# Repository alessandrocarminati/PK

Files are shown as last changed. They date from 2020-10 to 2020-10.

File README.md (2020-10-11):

# Password keeper 
The password keeper is a toy device for storing the personal password, and type them quickly.
The device can store up to 8 different passwords, no more than 16 chars each with 8 tags no more than 8 chars each.
One of the two buttons on the device allows the user to select the intended password and while the other allows to type it.
One two lines Hitachi HD44780 compatible display allows the user to see the tag associated with the password before typing it.
Relevant features of this project are as follows:
* The main MCU is an AVR ATTINY 85 @16MHz
* Just one MCU GPIO is used to drive the display
* The device presents itself as a keyboard, and it allows using just the USB keyboard interface to update the password DB
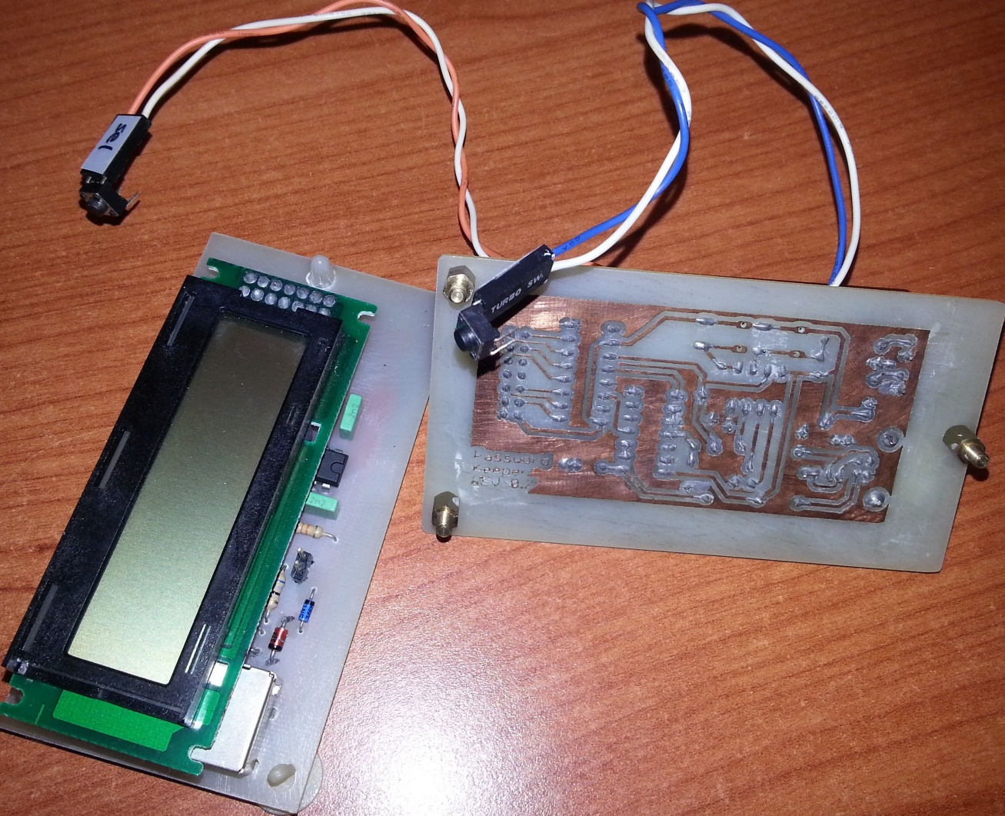
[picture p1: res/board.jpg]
design


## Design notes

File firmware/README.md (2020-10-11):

# Passwork keeper device firmware
The firmware is meant to be compiled by using the Arduino IDE and the Adafruit Trinket extension

https://adafruit.github.io/arduino-board-index/package_adafruit_index.json

The target AtTiny85 is assumed to be 16MHz, and to have the USBtinyISP boot loader already installed.

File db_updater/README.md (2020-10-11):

# Passwork keeper database updater
Straightforward utility. It gets a password file as argument and pushes it into the device using keyboard LEDs.
The three LEDs on the keyboard are used as lines of synchronous serial communication.
**makedb.c**  can be used to create a new database
**update.c** is the utility used for the actual update

*Example*
```
[edit makedb.c and put your password data. Remeber data is meant to be usb keyboard scancodes. Refer to usb_hid_keys.h]
gcc -o makedb makedb.c
./makedb >data
gcc -o updater updater.c
./updater data
```

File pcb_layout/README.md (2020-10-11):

#Password keeper PCB
The current repository implements the following schema

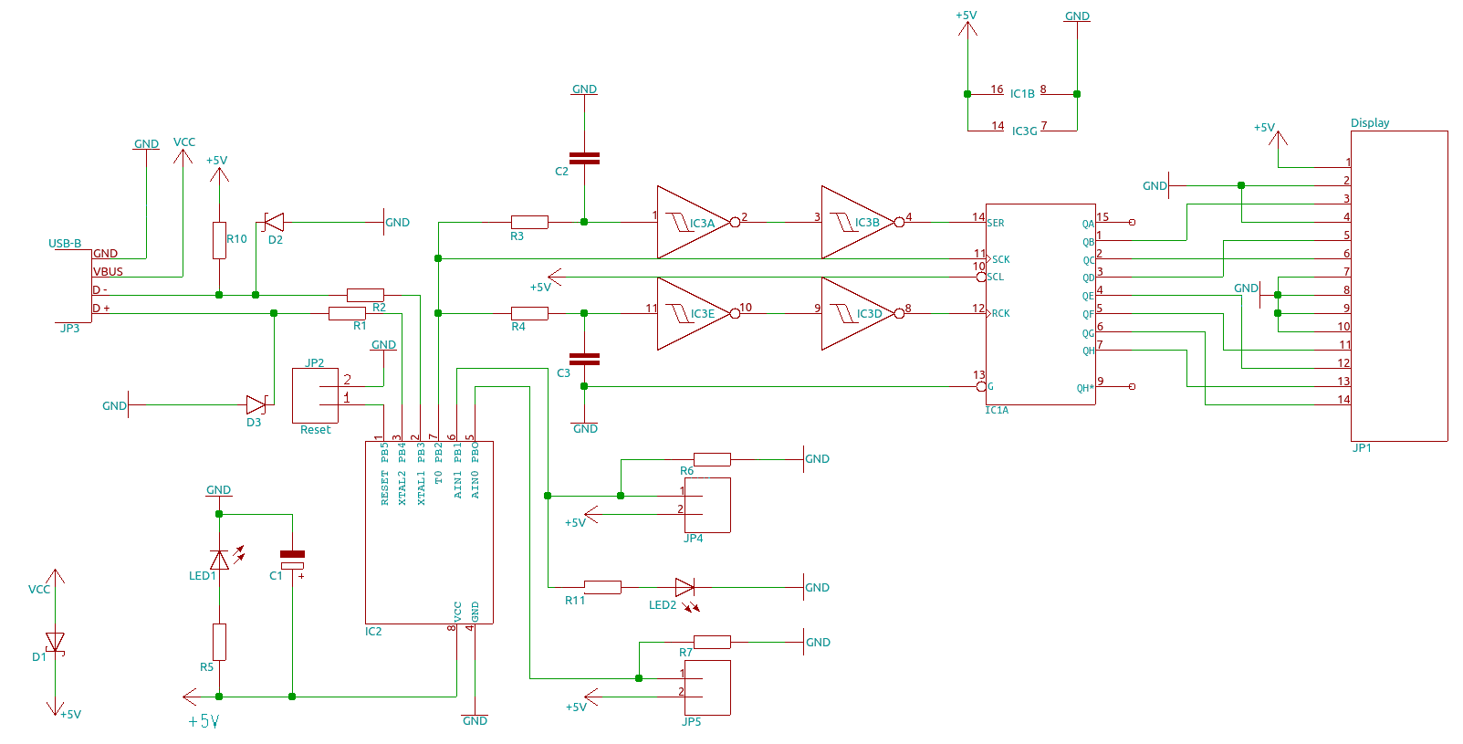
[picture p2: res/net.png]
NET


Because it is printed by hand, an effort is made to keep it single face.

Here the routed PCB

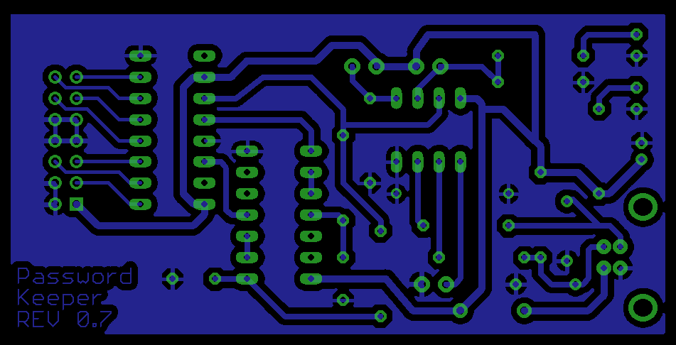
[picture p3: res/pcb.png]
LAYOUT


# BOM
| ID | Name | Package | Qty | Designation
|----|---|---|-----|---
|  1 | IC1 | DIL16 | 1 | 74HC595N
|  2 | IC2 | DIL08 | 1 | ATtiny85-20PU
|  3 | IC3 | DIL14 | 1 | CD40106BCN
|  4 | R1, R2 | 0207/10 | 2 | 68 $\Omega$
|  5 | R3 | 0207/10 | 1 | 33k $\Omega$
|  6 | R4 | 0207/10 | 1 | 220k $\Omega$
|  7 | R5 | 0207/10 | 1 | 560 $\Omega$ 
|  8 | R6, R7 | 0207/10 | 2 | 10k $\Omega$
|  9 | R10 | 0207/10 | 1 | 1.5k $\Omega$ 
| 10 | R11 | 0207/10 | 1 | 470 $\Omega$ 
| 11 | D1 | DO35 | 1 | 1N581
| 12 | D2, D3 | DO35 | 2 | 1N5227B-TR
| 13 | LED1 | LED5MM | 1 | Power
| 14 | LED2 | LED5MM | 1 | ACT
| 15 | C1 | E2-5 | 1 | 10$\mu$F
| 16 | C2, C3 | C050-024X044 | 2 | 2.2nF
| 17 | J1 | 2X07_LOCK | 1 | Display Connector
| 18 | JP3 | USB-B-PTH | 1 | USB-B
| 19 | JP2 | 1X02_LOCK | 1 | Reset
| 20 | JP4 | 1X02_LOCK | 1 | Button1
| 21 | JP5 | 1X02_LOCK | 1 | Button2
| 22 | DISPLAY  | NA | 1 | LM16211

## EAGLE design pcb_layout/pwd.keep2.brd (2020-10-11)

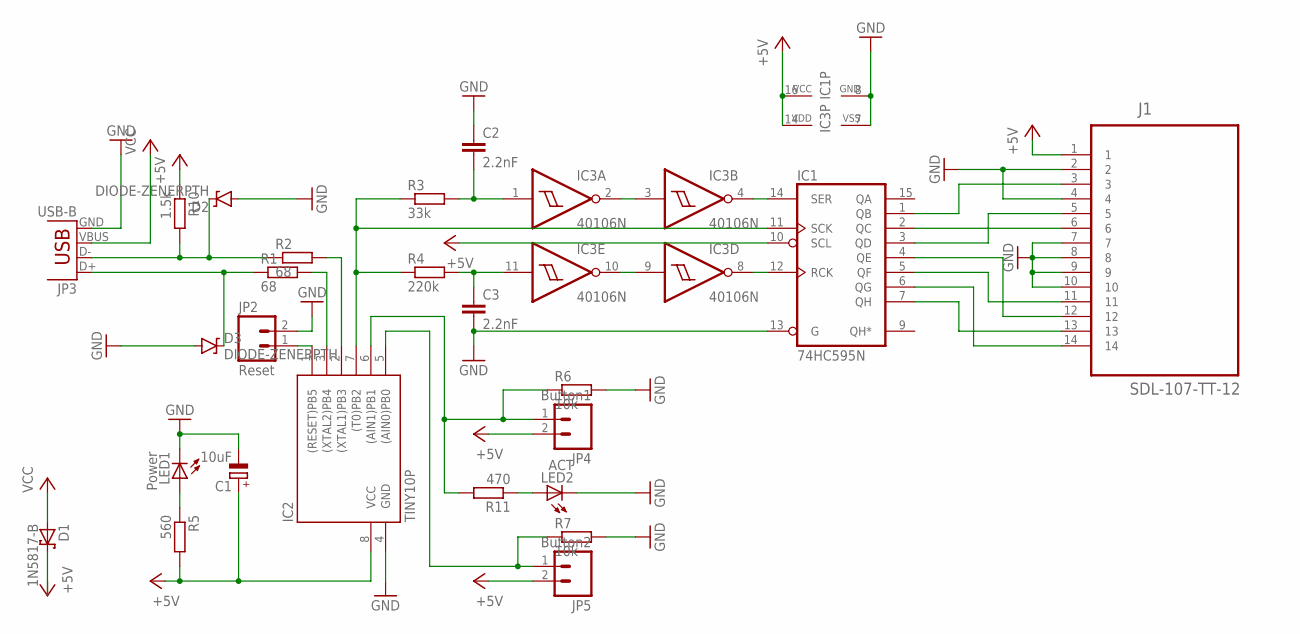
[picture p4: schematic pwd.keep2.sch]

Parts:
C1: 10uF; E2-5
C2, C3: 2.2nF; C050-024X044
D1: 1N5817-B; DO41-7.6
D2, D3: DIODE-ZENERPTH; DIODE-ZENER
IC1: 74HC595N; DIL16
IC2: TINY10P; DIL08
IC3: 40106N; DIL14
J1: SDL-107-TT-12; SAMTEC_SDL-107-TT-12
JP2: Reset; 1X02_LOCK
JP3: USB-B; USB-B-PTH
JP4: Button1; 1X02_LOCK
JP5: Button2; 1X02_LOCK
LED1: Power; LED5MM
LED2: ACT; LED5MM
R1, R2: 68; 0207/10
R3: 33k; 0207/10
R4: 220k; 0207/10
R5: 560; 0207/10
R6, R7: 10k; 0207/10
R10: 1.5k; 0207/10
R11: 470; 0207/10

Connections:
+5V: C1.+, D1.C, IC1.10 (SCL), IC1.16 (VCC), IC2.8 (VCC), IC3.14 (VDD), J1.1, JP4.2, JP5.2, R5.2, R10.1
GND: C1.-, C2.1, C3.2, D2.P$2 (A), D3.P$2 (A), IC1.8 (GND), IC1.13 (G), IC2.4 (GND), IC3.7 (VSS), J1.2, J1.4, J1.7, J1.8, J1.9, J1.10, JP2.2, JP3.GND, LED1.K (C), LED2.K (C), R6.2, R7.2
unnamed: IC1.7 (QH), J1.13
unnamed: IC1.6 (QG), J1.14
unnamed: IC1.5 (QF), J1.11
unnamed: IC1.4 (QE), J1.12
unnamed: IC1.3 (QD), J1.5
unnamed: IC1.2 (QC), J1.6
unnamed: IC1.1 (QB), J1.3
unnamed: D3.P$1 (C), JP3.D+, R1.1
unnamed: IC2.3 ((XTAL2)PB4), R1.2
unnamed: D2.P$1 (C), JP3.D-, R2.1, R10.2
unnamed: IC2.2 ((XTAL1)PB3), R2.2
unnamed: IC2.1 ((RESET)PB5), JP2.1
unnamed: LED2.A, R11.1
unnamed: LED1.A, R5.1
unnamed: IC1.11 (SCK), IC2.7 ((T0)PB2), R3.1, R4.1
unnamed: C3.1, IC3.11 (I), R4.2
unnamed: C2.2, IC3.1 (I), R3.2
unnamed: IC2.6 ((AIN1)PB1), JP4.1, R6.1, R11.2
unnamed: IC3.2 (O), IC3.3 (I)
unnamed: IC2.5 ((AIN0)PB0), JP5.1, R7.1
unnamed: IC1.14 (SER), IC3.4 (O)
unnamed: IC1.12 (RCK), IC3.8 (O)
unnamed: IC3.9 (I), IC3.10 (O)
VCC: D1.A, JP3.VBUS

Board: 2 copper layers, 25 parts (0 on the bottom side), 26 nets, no tracks yet.

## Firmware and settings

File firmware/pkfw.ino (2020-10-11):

#include <TrinketKeyboard.h>
#include <EEPROM.h>
#define SETUP_IDX 8
#define BROWSEPIN 0
#define ENTERPIN 1
#define DATAPIN 2
char UPDATE_STR[] = {'U','p','d','a','t','e',' ','p','s','w',' ','D','B','\0','\0','\0'};
char label[8];
char pswd[16];
unsigned char index, releasedB,releasedE;


void LCD1WireSend(unsigned char b) {
	char i;  //28 0010 1000

	for (i=7;i>0;i--) {
		if ((b>>i)&0x1) { // send 1
			digitalWrite(DATAPIN,LOW);
			delayMicroseconds(2);
			digitalWrite(DATAPIN,HIGH);
			delayMicroseconds(200);
			} else { // send 0
				digitalWrite(DATAPIN,LOW);
				delayMicroseconds(120);
				digitalWrite(DATAPIN,HIGH);
				delayMicroseconds(480);
				}
			}
	// send latch
	digitalWrite(DATAPIN,LOW);
	delayMicroseconds(460);
	digitalWrite(DATAPIN,HIGH);
	delayMicroseconds(1700);
	TrinketKeyboard.poll();
}

void LCDinit() {

	LCD1WireSend(0x28);
	LCD1WireSend(0x20); //init 4bit mode
	LCD1WireSend(0x08); 
	LCD1WireSend(0x00); //first nibble
	LCD1WireSend(0xc8);
	LCD1WireSend(0xc0); //second nibble clearscreen home show cursor
}

void LCDChar(unsigned char c) {
	LCD1WireSend( (c & 0xf0) | 0x0a);
	LCD1WireSend( (c & 0xf0) | 0x02);
	LCD1WireSend( c<<4 | 0x0a);
	LCD1WireSend( c<<4 | 0x02);
}

void LCDWrite(char *st) {

	while (*st != 0) {
		LCDChar(*st);
		st++;
		}
}

void LCDClear() {

	LCD1WireSend(0x08);
	LCD1WireSend(0x00); //first nibble
	LCD1WireSend(0xf8);
	LCD1WireSend(0xf0); //second nibble clearscreen home show cursor
}

void LCDGotoN(unsigned char n){

	 LCD1WireSend(0x88|n&70);
	 LCD1WireSend(0x80|n&70);
	 LCD1WireSend(n<<4|0x8);
	 LCD1WireSend(n<<4);
}

void LCDCLS() {
	LCD1WireSend(0x08);
	LCD1WireSend(0x00);
	LCD1WireSend(0x18);
	LCD1WireSend(0x10);
}


void evaluateBitString(unsigned char b, char *buf) {

	for (int i=0; i<8; i++) 
		if ((b>>i)&1) *(buf+7-i)=0x31; 
			else *(buf+7-i)=0x30;
}

/*
 * serial communication over keyboard status leds
 * use CapsLock as MOSI
   *    NumLock as CLK
   * ScrollLock as LATCH
 */

void download_psw_db() {
	char inprogress=1;
	char prevClk;
	char buffer_sreg;
	unsigned char cnt=0;

	LCDCLS();
	LCDWrite("Updating DB...");

	while (inprogress) {
		TrinketKeyboard.poll();
		unsigned char led=TrinketKeyboard.getLEDstate();
		if (!(led & KB_LED_NUM) && prevClk) {
			buffer_sreg=(buffer_sreg<<1) |(led & KB_LED_CAPS?1:0);
			if ((led & KB_LED_SCROLL)) {
				EEPROM.write(cnt,buffer_sreg);
				cnt++;
				digitalWrite(ENTERPIN,cnt&1);
				if (cnt>=192) inprogress=0;
				}
                                                          
			}
		prevClk=(led & KB_LED_NUM)?1:0;
		}
}

void send_keystrokes(char *psw) {
	unsigned char i=0;

	while (*(psw+i)) {
		TrinketKeyboard.pressKey(*(psw+i)>>6?2:0,*(psw+i)&0x3f);
		TrinketKeyboard.pressKey(0, 0);
		i++;
		}
}

void setup() {

	TrinketKeyboard.begin();
	pinMode(DATAPIN,OUTPUT);
	pinMode(BROWSEPIN,INPUT);
	pinMode(ENTERPIN,INPUT);
	releasedB=1;
	releasedE=1;
	index=0;
	LCDinit();
	LCDWrite("Password Keeper");
	LCDGotoN(0x40);
	LCDWrite("Rev 0.1");
	for (char i=0;i<20;i++) {
		TrinketKeyboard.poll();
		delay(100);
		}
	LCDCLS();
	for(char i=0;i<8;i++) label[i]=EEPROM.read(8*index+i);
	LCDWrite(label);
}

void loop() {
	TrinketKeyboard.poll();
	if (digitalRead(BROWSEPIN) & releasedB ){
		index=(index+1);
		if (index>SETUP_IDX) index=0;
		LCDCLS();
		if (index!=SETUP_IDX) {
			for(char i=0;i<8;i++) label[i]=EEPROM.read(8*index+i);
			LCDWrite(label);
			} else LCDWrite(UPDATE_STR);
		releasedB=0;
		} else {
			if (!digitalRead(BROWSEPIN)) releasedB=1;
			}
	if (digitalRead(ENTERPIN) & releasedE ){
		if (index==SETUP_IDX) {
//			pinMode(ENTERPIN,OUTPUT);
			download_psw_db();
//			pinMode(ENTERPIN,INPUT);
			index=0;
			LCDCLS();
			for(char i=0;i<8;i++) label[i]=EEPROM.read(8*index+i);
			LCDWrite(label);
			} else {
				for(char i=0;i<16;i++) pswd[i]=EEPROM.read(64+16*index+i);
				send_keystrokes(pswd);
				}
			releasedE=0;
			} else {
				if (!digitalRead(ENTERPIN)) releasedE=1;
				}
}

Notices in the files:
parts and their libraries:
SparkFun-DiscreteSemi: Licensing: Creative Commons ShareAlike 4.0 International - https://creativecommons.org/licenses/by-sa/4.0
